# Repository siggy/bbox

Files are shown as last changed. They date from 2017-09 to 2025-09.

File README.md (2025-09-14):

# Beatboxer <!-- omit from toc -->

A human-sized drum machine built with a Raspberry Pi, an Adafruit Feather SCORPIO, NeoPixels, and Go.

- [Raspberry PI Setup](#raspberry-pi-setup)
  - [OS](#os)
    - [First Boot](#first-boot)
    - [Faster boot](#faster-boot)
    - [Code](#code)
    - [USB Audio](#usb-audio)
      - [bbox-style sound card](#bbox-style-sound-card)
      - [baux-style sound card](#baux-style-sound-card)
      - [Test](#test)
    - [Audio support for Go](#audio-support-for-go)
- [Run](#run)
- [Build](#build)
- [Auto boot with keyboard attach](#auto-boot-with-keyboard-attach)
  - [Auto boot baux](#auto-boot-baux)
- [Connectivity](#connectivity)
  - [Configure to connect over ethernet](#configure-to-connect-over-ethernet)
  - [Configure the Pi to connect as Wifi AP](#configure-the-pi-to-connect-as-wifi-ap)
    - [Switch the Pi back to connecting to the internet with wifi](#switch-the-pi-back-to-connecting-to-the-internet-with-wifi)
- [Docs](#docs)
- [Credits](#credits)
- [TODO](#todo)

# Raspberry PI Setup

## OS

1. Install Raspberry Pi Imager: https://www.raspberrypi.com/software/
2. Choose `Raspberry Pi 5`, `Raspberry Pi OS Lite (64-bit)` and
   `USB Mass Storage` in the Imager
3. Select:
  - `Set hostname` to `raspberrypi`
  - `Set username and password`: `sig`
  - `Set locale` to `en_US.UTF-8`
  - `Configure wireless LAN`
  - `Enable SSH`: `Allow public-key authentication only`

### First Boot

```bash
HOSTNAME=raspberrypi
HOSTNAME=raspberrypi5-2
HOSTNAME=raspberrypi5-3
HOSTNAME=raspberrypi5-4
HOSTNAME=raspberrypi5-5
HOSTNAME=raspberrypi5-6

ssh sig@raspberrypi.local
ssh sig@$HOSTNAME.local
ssh sig@raspberrypi5-5.local

# install packages
sudo apt-get update
sudo sed -i 's/^# *\(en_US.UTF-8 UTF-8\)/\1/' /etc/locale.gen
sudo locale-gen
sudo dpkg-reconfigure locales
sudo apt-get install -y git tmux vim locales

# GITHUB_TOKEN=

git clone https://github.com/siggy/dotfiles.git ~/code/dotfiles
cp ~/code/dotfiles/.local.bash.pi ~/.local.bash
cp ~/code/dotfiles/.curlrc        ~/
cp ~/code/dotfiles/.gitconfig     ~/
cp ~/code/dotfiles/.tmux.conf     ~/
cp ~/code/dotfiles/.vimrc         ~/
cp ~/code/dotfiles/.wgetrc        ~/

sed -i '/^[[:space:]]*helper = osxkeychain/ s/^/#/' ~/.gitconfig

mkdir -p ~/.vim/backups
mkdir -p ~/.vim/swaps
cp -a ~/code/dotfiles/.vim/colors ~/.vim

echo "[[ -s ${HOME}/.local.bash ]] && source ${HOME}/.local.bash" >> ~/.profile
```

### Faster boot

```bash
sudo systemctl disable ModemManager.service
sudo systemctl disable NetworkManager-wait-online.service
sudo systemctl disable bluetooth.service
sudo systemctl disable dphys-swapfile.service
sudo systemctl disable fake-hwclock.service
sudo systemctl disable systemd-binfmt.service
sudo systemctl mask sys-kernel-debug.mount sys-kernel-tracing.mount
sudo systemctl mask rpi-eeprom-update
sudo systemctl disable e2scrub_reap.service
sudo dphys-swapfile swapoff
sudo apt-get -y purge modemmanager bluez triggerhappy
sudo apt-get -y autoremove --purge

sudo grep -q 'rootdelay=' /boot/firmware/cmdline.txt \
  || sudo sed -i 's/$/ rootdelay=2 modules-load=dwc2/' /boot/firmware/cmdline.txt

echo "PollIntervalMinSec=600" | sudo tee -a /etc/systemd/timesyncd.conf
```

### Code

```bash
curl -L -o /tmp/go1.24.4.linux-arm64.tar.gz https://go.dev/dl/go1.24.4.linux-arm64.tar.gz
sudo rm -rf /usr/local/go && sudo tar -C /usr/local -xzf /tmp/go1.24.4.linux-arm64.tar.gz
export PATH=$PATH:/usr/local/go/bin

mkdir -p ~/code/
git clone https://github.com/siggy/bbox.git ~/code/bbox
```

### USB Audio

#### bbox-style sound card

For MCSPER USB to 3.5mm Audio Jack Adapter.

Plug in USB audio device and run:
```bash
sudo tee /etc/asound.conf > /dev/null <<'EOF'
pcm.!default {
  type plug
  slave.pcm "dmix:Audio,0"
}

ctl.!default {
  type hw
  card "Audio"
}
EOF

amixer
amixer -c 0 scontrols
amixer -c 0 set PCM 95%
```

#### baux-style sound card

For Plugable USB Audio Adapter with 3.5mm Speaker-Headphone and Microphone Jack.

Plug in USB audio device and run:
```bash
sudo tee /etc/asound.conf > /dev/null <<'EOF'
pcm.!default {
  type plug
  slave.pcm "dmix:Device,0"
}

ctl.!default {
  type hw
  card "Device"
}
EOF
```

#### Test

```bash
aplay /usr/share/sounds/alsa/Front_Center.wav
```

### Audio support for Go

```bash
sudo apt-get install -y libasound2-dev
```

# Run

```bash
go run cmd/bbox/main.go --fake-leds
```

# Build

```bash
go build -o /home/sig/bin/bbox cmd/bbox/main.go
```

# Auto boot with keyboard attach

```bash
cat <<'EOF' >> ~/.profile

if [ "$(tty)" = "/dev/tty1" ]; then
  tmux attach -t bbox || tmux new-session -s bbox "bash -c '/home/sig/bin/bbox; exec bash'"
fi
EOF
```

```bash
sudo mkdir -p /etc/systemd/system/getty@tty1.service.d
cat <<EOF | sudo tee /etc/systemd/system/getty@tty1.service.d/override.conf
[Service]
ExecStart=
ExecStart=-/sbin/agetty --autologin sig --noclear %I \$TERM
EOF

sudo systemctl daemon-reload
sudo reboot
```

## Auto boot baux

```bash
cat <<'EOF' >> ~/.profile

export MINIAUDIO_ALSA_NO_MMAP=1
if [ "$(tty)" = "/dev/tty1" ]; then
  tmux attach -t bbox || tmux new-session -s bbox "bash -c '/home/sig/bin/baux; exec bash'"
fi
EOF
```

# Connectivity

## Configure to connect over ethernet

```bash
IP=192.168.2.2
IP=192.168.2.3
IP=192.168.2.4
IP=192.168.2.5
IP=192.168.2.6
sudo nmcli con add type ethernet ifname eth0 con-name eth0-static ipv4.addresses $IP/24 ipv4.method manual
sudo nmcli con up eth0-static
```

```bash
HOSTNAME=raspberrypi
HOSTNAME=raspberrypi5-2
HOSTNAME=raspberrypi5-3
HOSTNAME=raspberrypi5-4
HOSTNAME=raspberrypi5-5
HOSTNAME=raspberrypi5-6
IP=192.168.2.2
IP=192.168.2.2
IP=192.168.2.3
IP=192.168.2.4
IP=192.168.2.5
IP=192.168.2.6
alias pi="ssh sig@$HOSTNAME.local"
alias pieth="ssh sig@$IP"
```

## Configure the Pi to connect as Wifi AP

```bash
SSID=sigpi
SSID=sigpi5-2
SSID=sigpi5-3
SSID=sigpi5-4
SSID=sigpi5-5
SSID=sigpi5-6
rfkill list
sudo rfkill unblock wifi
rfkill list
sudo nmcli radio wifi on
sudo nmcli dev wifi hotspot ifname wlan0 ssid $SSID password showmethepi
nmcli dev wifi show-password
sudo nmcli connection modify Hotspot autoconnect yes
```

From laptop:
```bash
HOSTNAME=raspberrypi5-4
ssh sig@$HOSTNAME.local
```

### Switch the Pi back to connecting to the internet with wifi

```bash
nmcli connection show
sudo nmcli connection down Hotspot
```

# Docs

```bash
docker run --rm \
  --volume="$PWD/docs:/srv/jekyll:Z" \
  --publish 4000:4000 \
  --publish 35729:35729 \
  -it jekyll/jekyll:4.2.2 \
  jekyll serve --source /srv/jekyll --livereload

open http://0.0.0.0:4000/bbox/
```

# Credits

- [amplitude](pkg/amplitude) courtesy of (https://github.com/johnusher)
- Hardware keyboard courtesy of (https://github.com/kodachi614/macropaw)
- [wavs](wavs) courtesy of (http://99sounds.org/drum-samples/)

# TODO

- proper LED simulator

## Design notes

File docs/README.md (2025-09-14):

---
layout: default
title: "Beatboxer: A human-sized drum machine built with a Raspberry Pi, a Feather SCORPIO, NeoPixels, and Go"
permalink: /
---

<style>
  :root { color-scheme: dark; }
  html, body, h1, h2 { background:#202124; color:#619e4e; }
  a { color:#b88de3; }
  a:visited { color:#a774d6; }
  pre, code { background:#111; color:#619e4e; }
  hr { border-color:#333; }
</style>

# Beatboxer: A human-sized drum machine built with a Raspberry Pi, a Feather SCORPIO, NeoPixels, and Go

<iframe width="560" height="315" src="https://www.youtube.com/embed/MepepCV4EUw" frameborder="0" allowfullscreen></iframe>

# Prior Art

Inspired by Nine Inch Nails' Echoplex drum machine:

<iframe width="560" height="315" src="https://www.youtube.com/embed/6O_92BTrUcA" frameborder="0" allowfullscreen></iframe>
---
First implementation in JavaScript at [sig.gy/beatboxer](https://sig.gy/beatboxer):

<iframe width="900" height="315" src="https://sig.gy/beatboxer" frameborder="0" allowfullscreen></iframe>

# Hardware

- [Raspberry Pi 5](https://www.raspberrypi.com/products/raspberry-pi-5/)
- [Adafruit Feather RP2040 SCORPIO](https://www.adafruit.com/product/5650)
- 8x [NeoPixel 144 strands](https://www.adafruit.com/product/2847)
- [Custom MacroPaw keyboard](https://github.com/kodachi614/macropaw) by [@kodachi614](https://github.com/kodachi614)

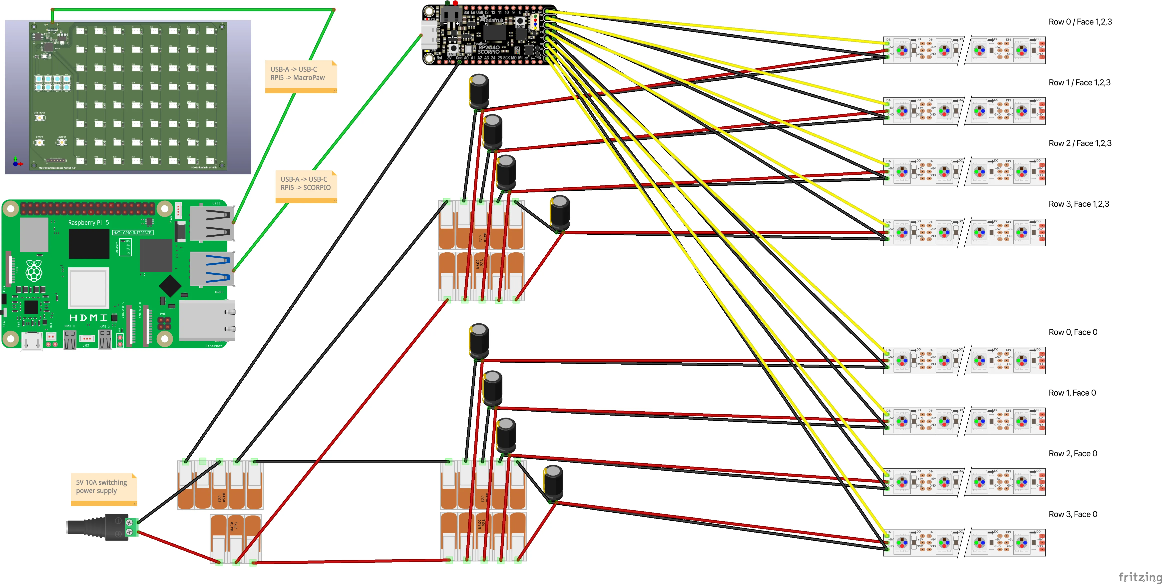
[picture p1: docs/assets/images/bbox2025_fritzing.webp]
Beatboxer 2025 Fritzing


<a href="assets/images/bbox2025_fritzing.fzz">Click here</a> to download the source Fritzing sketch file (requires the <a href="https://github.com/adafruit/Fritzing-Library">Adafruit Fritzing Library</a> and a <a href="https://github.com/siggy/macropaw/blob/main/Beatboxer/renders/macropaw_beatboxer_small.fzpz">custom MacroPaw part</a>).

# Software

- [main.go](https://github.com/siggy/bbox/blob/main/cmd/bbox/main.go)
- [generic program interface](https://github.com/siggy/bbox/blob/main/pkg/program/program.go#L16-L32)
- [SCORPIO integration](https://github.com/siggy/bbox/tree/main/scorpio)

# Build photos

<a
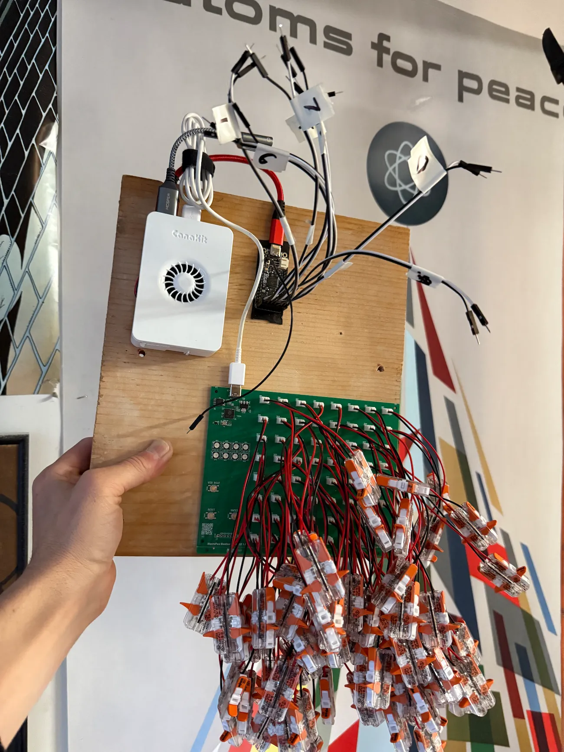
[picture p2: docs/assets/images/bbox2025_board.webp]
System on a board
href="assets/images/bbox2025_board.webp" data-lightbox="bbox2025" data-title="System on a board"></a><a
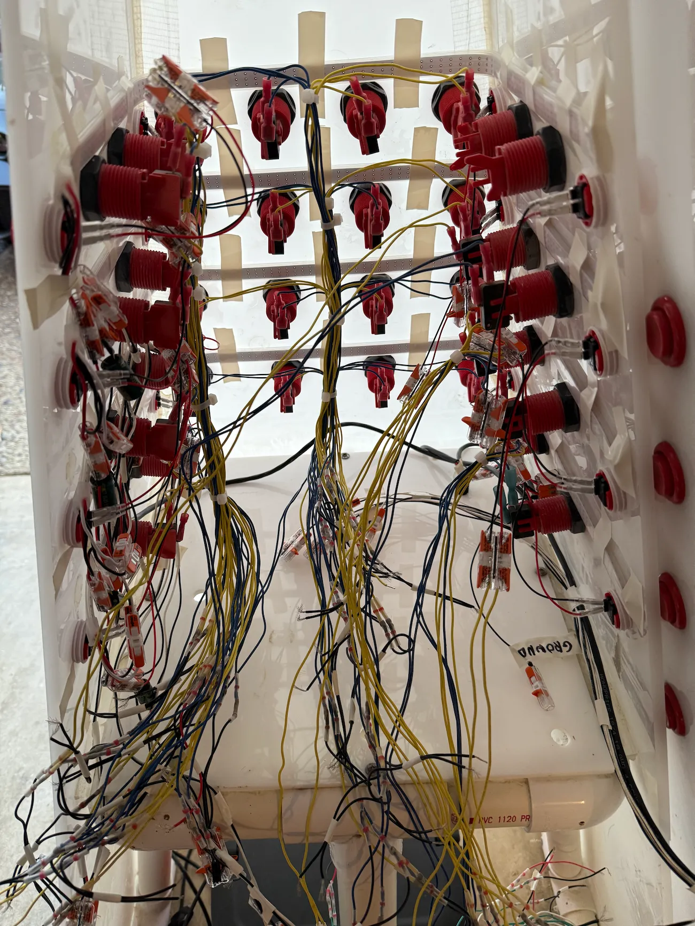
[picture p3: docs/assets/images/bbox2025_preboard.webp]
Pre-board installation
href="assets/images/bbox2025_preboard.webp" data-lightbox="bbox2025" data-title="Pre-board installation"></a><a
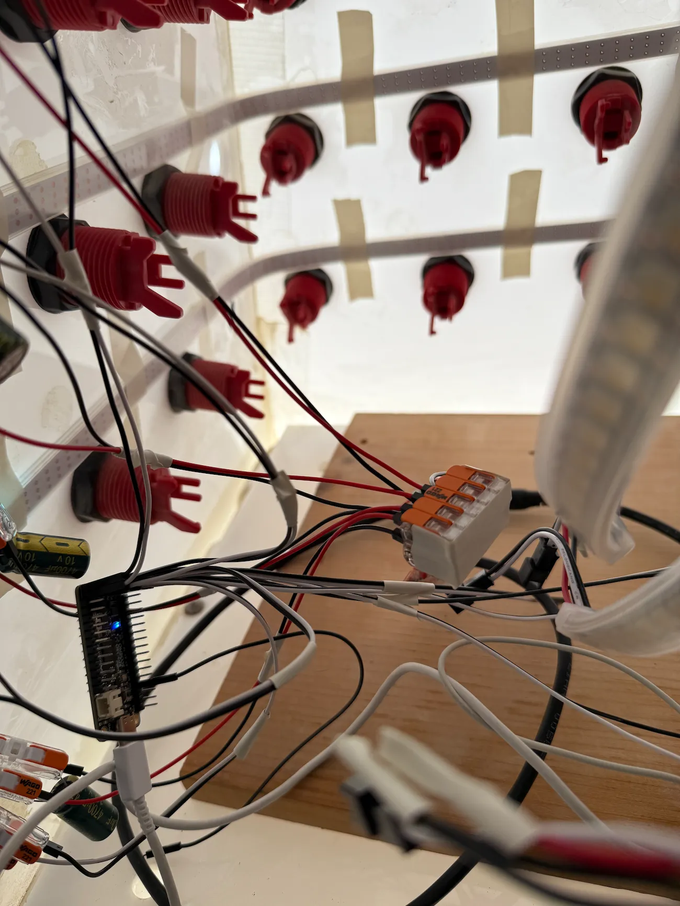
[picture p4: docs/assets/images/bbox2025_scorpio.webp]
SCORPIO install
href="assets/images/bbox2025_scorpio.webp" data-lightbox="bbox2025" data-title="SCORPIO install"></a><a
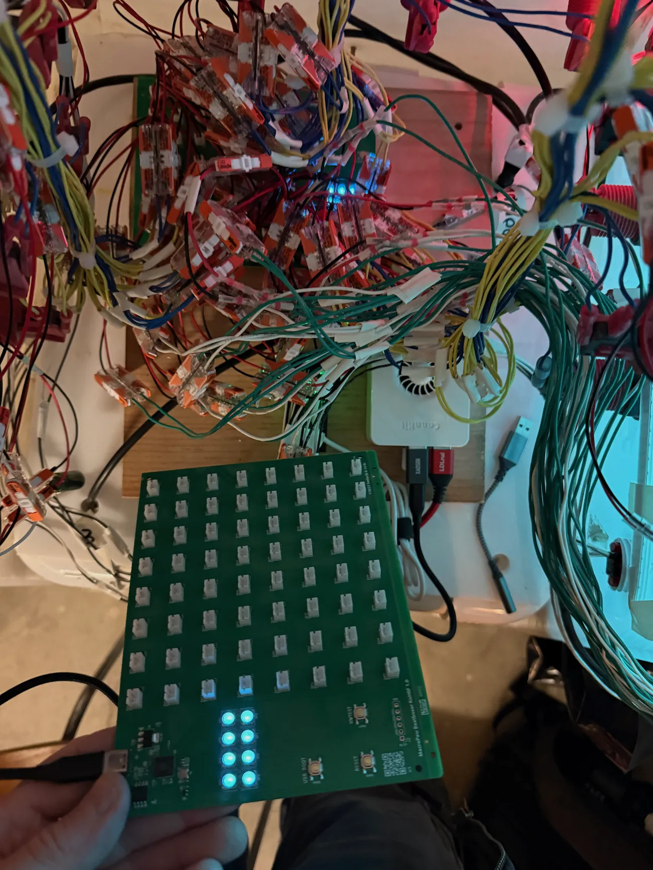
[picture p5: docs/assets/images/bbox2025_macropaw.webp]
MacroPaw install
href="assets/images/bbox2025_macropaw.webp" data-lightbox="bbox2025" data-title="MacroPaw install"></a><a
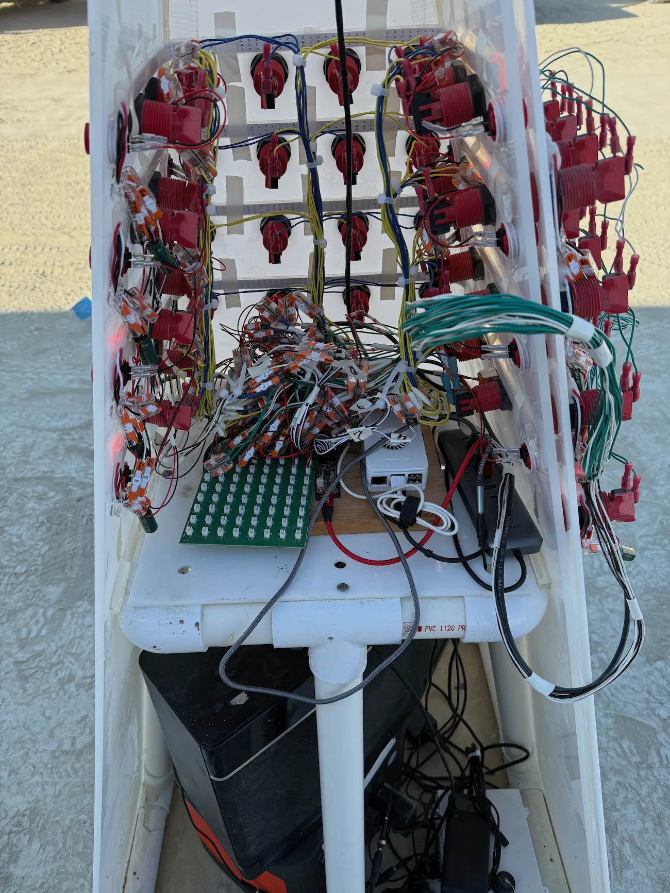
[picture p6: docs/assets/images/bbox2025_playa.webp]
Complete on playa
href="assets/images/bbox2025_playa.webp" data-lightbox="bbox2025" data-title="Complete on playa"></a><a
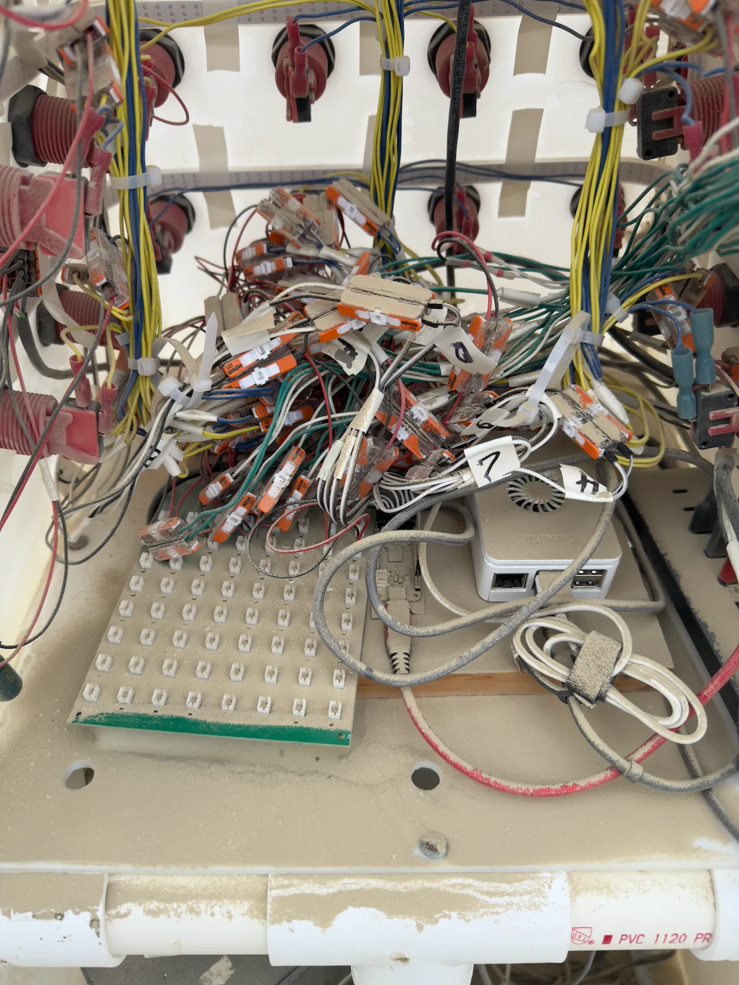
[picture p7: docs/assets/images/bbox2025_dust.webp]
After the dust storm
href="assets/images/bbox2025_dust.webp" data-lightbox="bbox2025" data-title="After the dust storm">
</a>

## Contact

<a href="https://github.com/siggy/bbox/issues">File an issue against this repo</a>, or find me at <a href="https://sig.gy">sig.gy</a>

This doc updated for 2025. For the original 2017-2018 writeup, see [Beatboxer 2017-2018](2017-2018).

<script src="https://ajax.googleapis.com/ajax/libs/jquery/2.1.4/jquery.min.js"></script>
<script src="assets/js/lightbox.min.js"></script>

<script>
  (function(i,s,o,g,r,a,m){i['GoogleAnalyticsObject']=r;i[r]=i[r]||function(){
  (i[r].q=i[r].q||[]).push(arguments)},i[r].l=1*new Date();a=s.createElement(o),
  m=s.getElementsByTagName(o)[0];a.async=1;a.src=g;m.parentNode.insertBefore(a,m)
  })(window,document,'script','https://www.google-analytics.com/analytics.js','ga');
  ga('create', 'UA-27834075-1', 'auto');
  ga('send', 'pageview');
</script>

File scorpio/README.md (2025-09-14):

# SCORPIO setup

## Configure board for Arduino

1. Arduino > Preferences
2. Add https://github.com/earlephilhower/arduino-pico/releases/download/global/package_rp2040_index.json
3. Boards Manager -> Raspberry Pi Pico/RP2040
4. Boards -> Adafruit Feather RP2040 SCORPIO
5. Sketch -> Include Library -> Manage Libraries ->
   - Adafruit_NeoPXL8
   - Adafruit_NeoPixel
   - Adafruit_ZeroDMA

## Arduino programs for SCORPIO

- [bbox.ino](bbox.ino): Main Beatboxer program.
- [baux.ino](baux.ino): Auxilliary Beatboxer program for driving the base and globe.
- [strand.ino](strand.ino): Standalone NeoPixel strand experiment.

## Debug from Pi

```bash
sudo fuser -v /dev/ttyACM0

sudo apt install picocom
picocom --baud 115200 /dev/ttyACM0
```

## Protocol

### Physical & Serial Settings

- Connection: USB‑CDC data port (/dev/ttyACM1 on the Pi, enabled via usb_cdc.enable(data=True) on the SCORPIO)
- Baud Rate: 115200 baud
- Data Bits: 8
- Parity: none
- Stop Bits: 1
- Flow Control: none

### Packet Framing

```
┌────────┬────────────┬───────────────┬───────────┐
│ 0xAA   │ 2-byte LEN │   PAYLOAD     │ CHECKSUM  │
│ Start  │ Big‑endian │ (LEN bytes)   │ 1 byte    │
└────────┴────────────┴───────────────┴───────────┘
```

1. Start Marker: 0xAA (1 byte)
2. Length: two‑byte unsigned integer, high‑byte first, total number of payload bytes
3. Payload: a sequence of N × 6 bytes (see §3)
4. Checksum: single byte = XOR of all payload bytes

### Payload Format

```
┌──────────┬──────────────┬───────┬───────┬───────┬───────┐
│ STRIP_ID │ PIXEL_INDEX  │  R    │  G    │  B    │  W    │
│  (0–7)   │ (0–length‑1) │(0–255)│(0–255)│(0–255)│(0–255)│
└──────────┴──────────────┴───────┴───────┴───────┴───────┘
```

- STRIP_ID (byte): Which NeoPixel strip (0…7)
- PIXEL_INDEX (byte): Which pixel on that strip
- R, G, B, W (bytes): The four color components

### Checksum

```go
var checksum byte
for _, b := range payload {
    checksum ^= b
}
```

### Sequence diagram

```
Pi (Go)                               SCORPIO
───────                               ───────

 every 30 ms tick:
   ┌───────────────────┐
   │ build diff list   │
   │ serialize payload │
   └───┬───────────────┘
       │ write([0xAA…])               loop:
       │────────────────────────────▶ check in_waiting
       │                              read start byte
       │                              read length bytes
       │                              read payload
       │                              read checksum
       │                              verify checksum
       │                              for each 6‑byte group:
       │                              └─update strip[pixel]
       │                              show() on all strips
```

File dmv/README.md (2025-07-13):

# DMV

Instructions for running DMV's LEDs.

## Arduino IDE

### Install

https://www.arduino.cc/en/software/

### Configure

Arduino Nano
Processor	ATmega328P (Old Bootloader)
Port: `/dev/cu.usbserial-110`

Install Adafruit NeoPixel library

### Install WS2812FX

```bash
git clone https://github.com/kitesurfer1404/WS2812FX.git
cp -a WS2812FX/src ~/Documents/Arduino/libraries/WS2812FX
```

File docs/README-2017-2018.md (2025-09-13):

---
layout: default
title: "Beatboxer: A human-sized drum machine built with a Raspberry Pi, LEDs, and Go"
permalink: /2017-2018
---

# Beatboxer: A human-sized drum machine built with a Raspberry Pi, LEDs, and Go

This is the story of building Beatboxer:

## 2017

<iframe width="560" height="315" src="https://www.youtube.com/embed/2gNIAz0s2dg" frameborder="0" allowfullscreen></iframe>

## 2018

<iframe width="560" height="315" src="https://www.youtube.com/embed/dJoFQYvSYmA" frameborder="0" allowfullscreen></iframe>

## Prior Art

### Nine Inch Nails

Around 2008 I saw Nine Inch Nails perform Echoplex using a drum machine that occupied the entire stage:

<iframe width="560" height="315" src="https://www.youtube.com/embed/6O_92BTrUcA" frameborder="0" allowfullscreen></iframe>

I loved it, I wanted to build something like it.

### Raspberry Pi

Eight years later in 2016 I had a converstion with my friend [Nick](https://github.com/hebnern) about his Arduino integration into [The Krawler](https://www.facebook.com/thekrawler/)'s fire poofers, he mentioned the lack of library and developer support being a pain point. He said he'd use a Raspberry Pi the next time, since it's pretty much just a Linux computer. This caught my attention. _It's a UNIX system, I know this._ That was the catalyst to look for an excuse to play with a Pi.

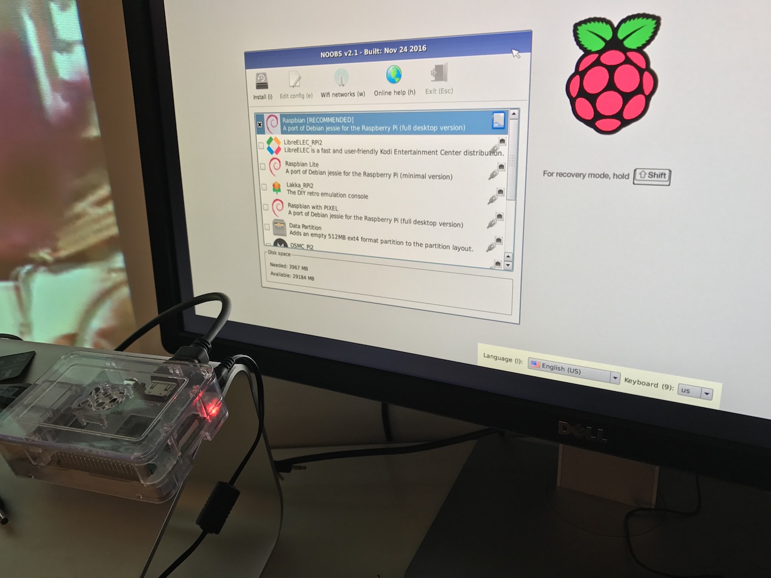
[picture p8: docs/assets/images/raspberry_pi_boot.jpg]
Raspberry Pi Boot
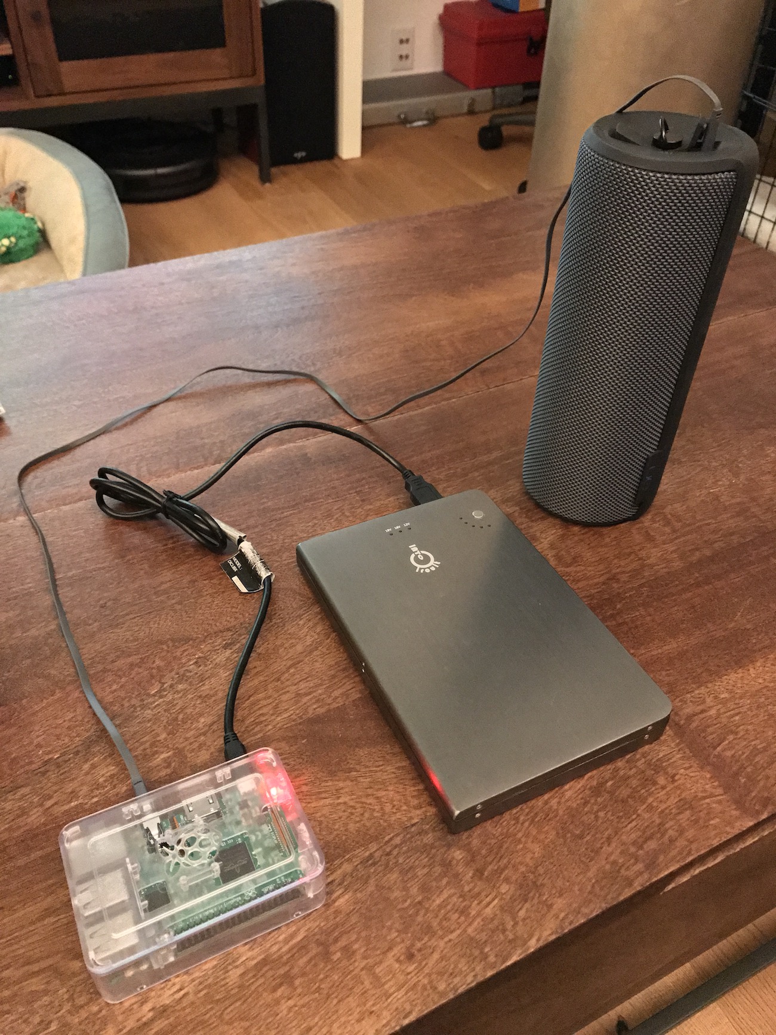
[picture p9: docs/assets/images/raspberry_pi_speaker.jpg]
Raspberry Pi Speaker
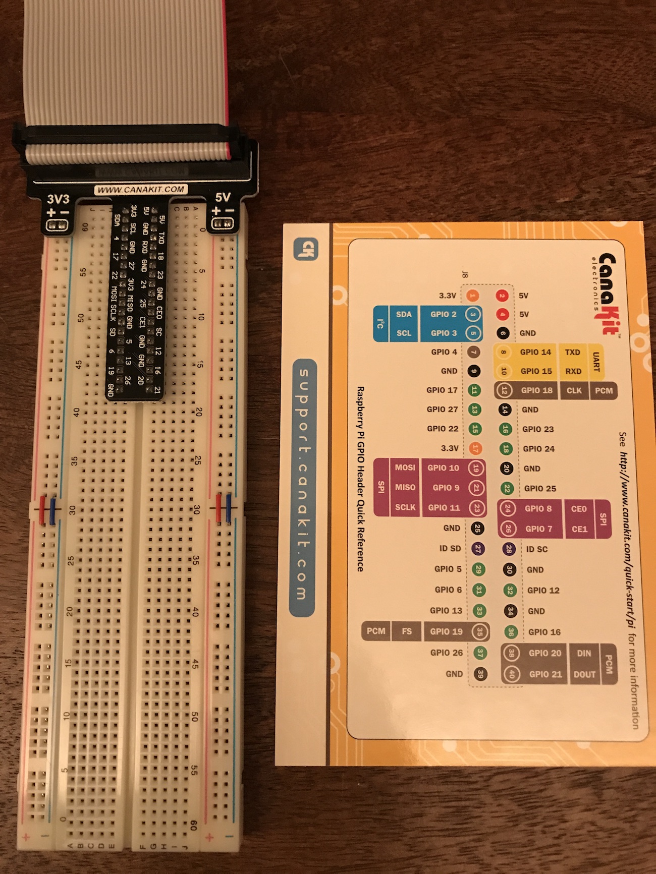
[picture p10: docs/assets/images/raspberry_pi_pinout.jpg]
Raspberry Pi Pinout


### Beatboxer in JavaScript

<a href="https://github.com/siggy/beatboxer/commit/17850ff889e607aba5941c5de58ecba9b342d5c0">About a week</a> after chatting with Nick, I attempted to replicate Nine Inch Nails' drum machine on a web page, using as little code as possible. The result was a few hundred lines of JavaScript, HTML, and CSS, I called it [Beatboxer](https://sig.gy/beatboxer/):

<iframe width="900" height="315" src="https://sig.gy/beatboxer/" frameborder="0" allowfullscreen></iframe>

This was a fun project, I learned a bit about [AudioContext](https://developer.mozilla.org/en-US/docs/Web/API/AudioContext) for playing sounds and [requestAnimationFrame](https://developer.mozilla.org/en-US/docs/Web/API/window/requestAnimationFrame) for timing.

## A rewrite in Go

[Go](https://golang.org/) has recently become a favorite programming language of mine. Rewriting Beatboxer in Go was a great excuse to play with the language a bit more.

Beatboxer transmits input from a keyboard to LEDs, a console renderer, and a drum loop. The Go language really shines here in allowing explicit definition of these concurrent threads, with communication via Go Channels. This whole architecture is summarized nicely in [Beatboxer's main](https://github.com/siggy/bbox/blob/master/cmd/bbox.go).

Reading and playing back audio files in Go turned out to be more work than in JavaScript. I eventually found a pair of excellent Go libraries, [youpy's go-wav](https://github.com/youpy/go-wav) for reading wavs, and [gordonklaus' Go bindings](https://github.com/gordonklaus/portaudio) for [PortAudio](http://portaudio.com/) for outputting sound.

I found an awesome collection of high quality drum samples at [99sounds.org](http://99sounds.org/drum-samples/). It's free for download. Throw them a donation if you appreciate their work. I found their 808 beats to be just want I needed. I reached out to confirm they were OK with me using their samples in a public art project, [Tomislav](https://twitter.com/bpblog) replied a few hours later with full support.

## Back to hardware

With a working prototype in Go, I returned to thinking about building a physical drum machine. [Burning Man 2017](https://burningman.org/) provided a concrete deadline for added motivation.

I began brainstorming a structure with my good friend [@yet](https://twitter.com/yet), who pointed out that a long, flat structure like the one used by Nine Inch Nails would not fare well in the gale-force winds of the Black Rock Desert. He suggested wrapping the drum machine into the shape of a phone booth, as a more compact structure would be much easier to build, transport, and support.

A few days later I described the project to my good friend [Jhon](http://www.jar-lab.com/). Jhon's background in electronics and industrial design exceeds just about anyone I know, and he immediately suggested I reshape the phone booth as a pyramid. I loved the idea. At the time I did not realize the added complexity a shape like this would require, but in the end it was worth it.

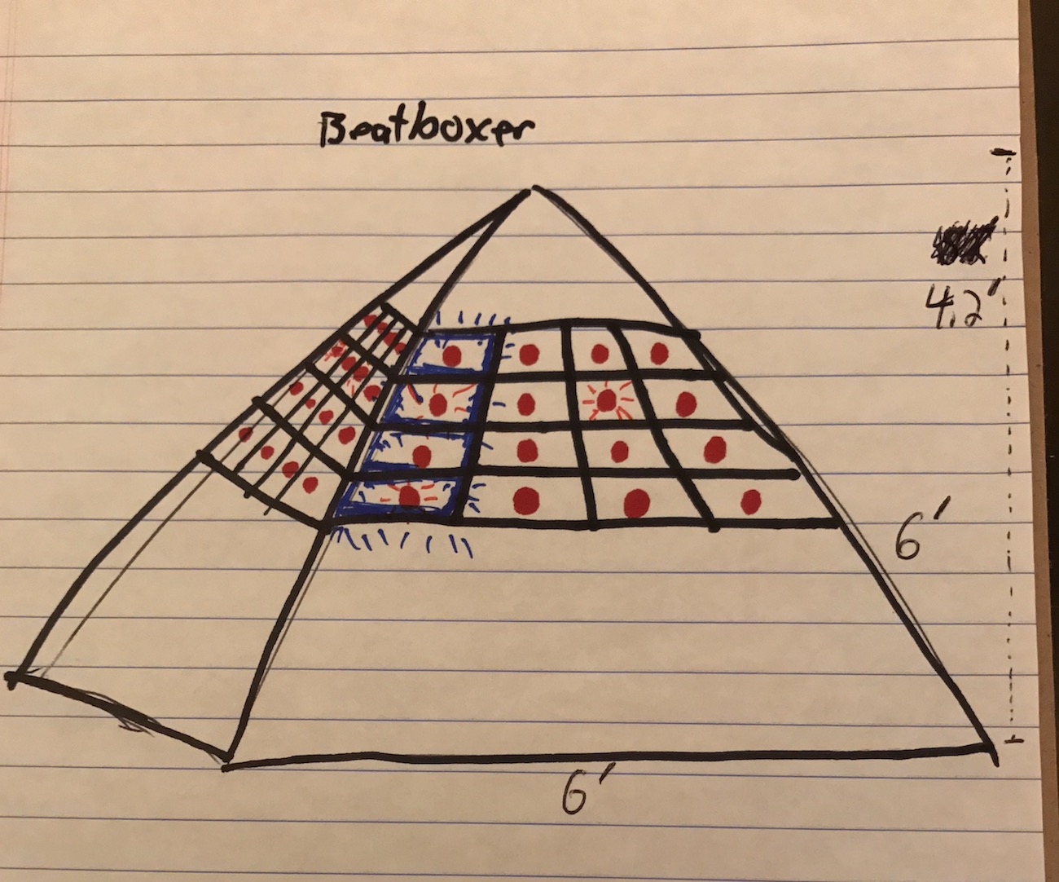
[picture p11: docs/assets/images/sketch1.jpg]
Sketch1
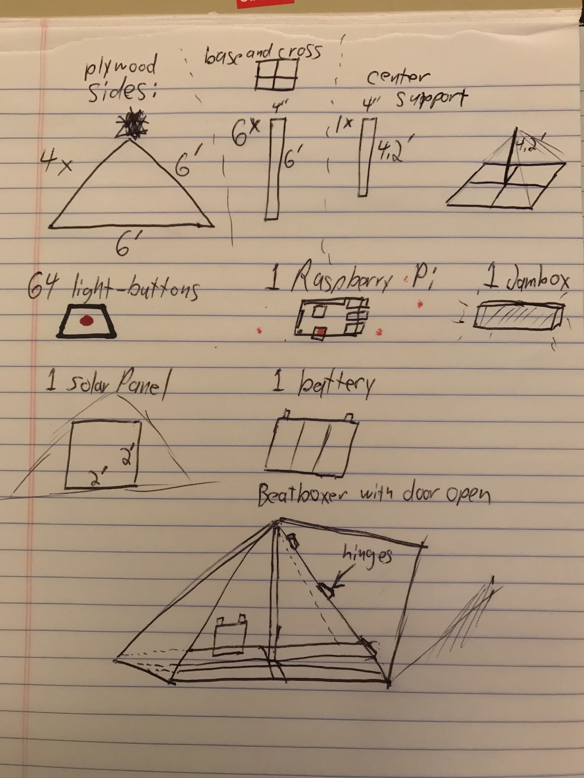
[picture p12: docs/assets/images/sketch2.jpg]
Sketch2
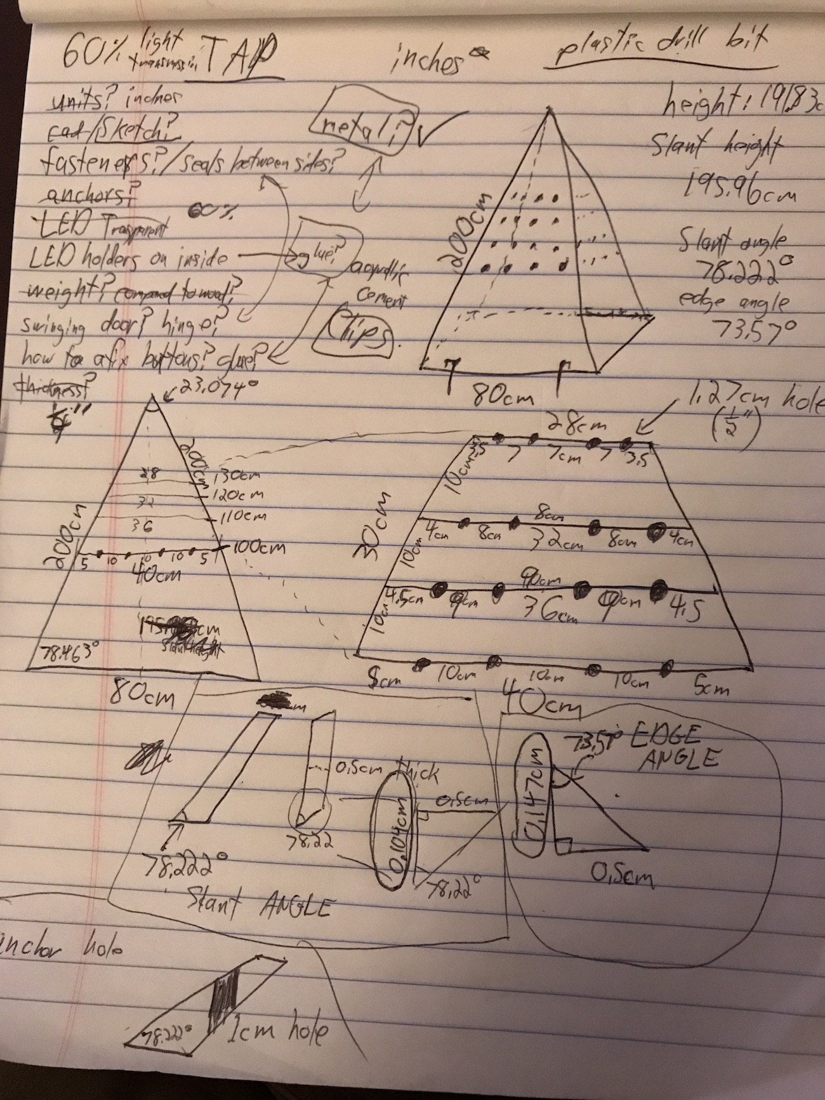
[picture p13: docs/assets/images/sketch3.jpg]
Sketch3


To build a pyramid, I naively thought I could simply design four triangles, do some linear calculations for the angles, and all would fit together. Fortunately my good friend and owner of Three Bears Furniture, [@jneaderhouser](https://twitter.com/jneaderhouser), pointed me to this excellent [compound miter calculator](http://www.pdxtex.com/canoe/compound.htm). This helped me determine that, based on triangles 6 feet tall by 2.5 feet wide, I needed 46.244° side bevels and 77.975° base bevels. I was able to confirm this all worked by building Beatboxer in SketchUp:

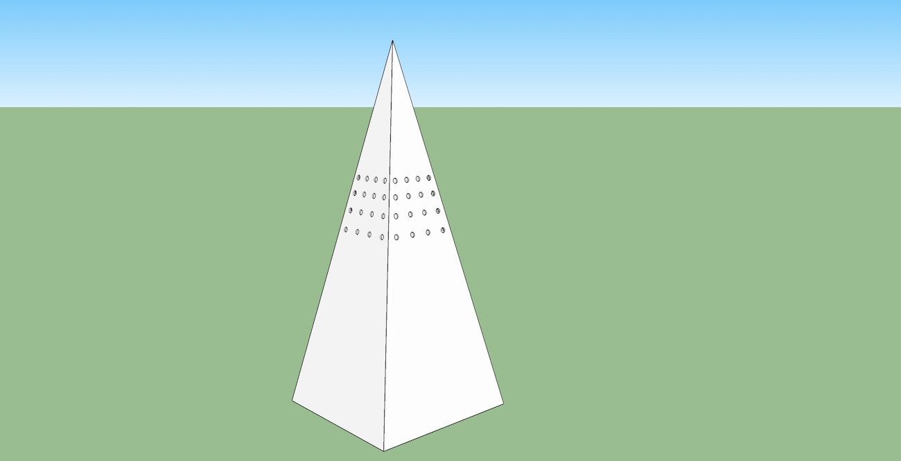
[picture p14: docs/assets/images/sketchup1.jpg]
SketchUp
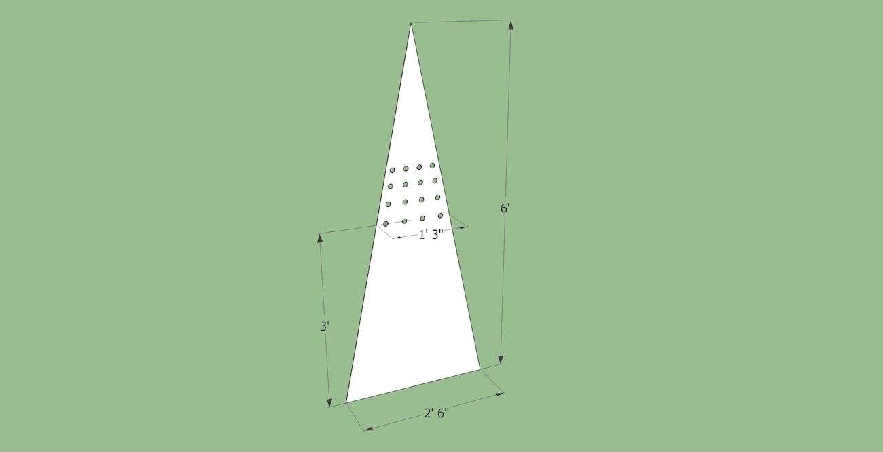
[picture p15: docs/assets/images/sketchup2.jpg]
SketchUp
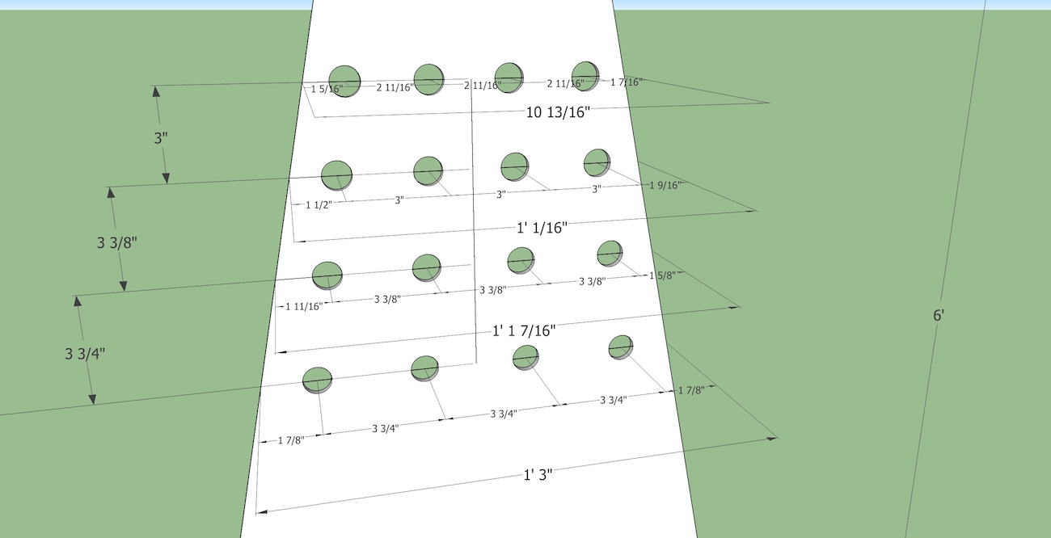
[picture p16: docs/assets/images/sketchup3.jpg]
SketchUp


For the full <a href="https://www.sketchup.com/">SketchUp</a> file, <a href="assets/images/bbox_sketchup.skp">click here</a>.

### Addressable LEDs

As the physical form continued to coalesce, I knew I'd need buttons to enable beats, and LEDs to provide feedback. I began researching addressable LEDs. Like Go, this was another domain where I was looking for a personal project to enable learning more about. Arduino seemed to be the platform of choice for working with LEDs. I opted to build the project around a Pi, aware that I was going a bit against the grain.

Fortunately the amazing folks at [Adafruit](https://www.adafruit.com/) had a tutorial on [controlling NeoPixel LEDs with a Raspberry Pi](https://learn.adafruit.com/neopixels-on-raspberry-pi). Even more fortuitious, the library used in the tutorial, [jgarff's rpi_ws281x](https://github.com/jgarff/rpi_ws281x), came with a Go wrapper!

I cannot emphasize enough how helpful [Adafruit](https://www.adafruit.com/) is for projects such as these. Their tutorials and documentation are awesome, and they provide all the materials needed to follow along.

Controlling [NeoPixels](https://www.adafruit.com/category/168) from a Pi requires building a circuit board, something I had zero experience with. I again enlisted [@yet](https://twitter.com/yet)'s help to learn how to solder wires, chips, and resistors. In short order we had a Pi controlling [NeoPixels](https://www.adafruit.com/category/168).

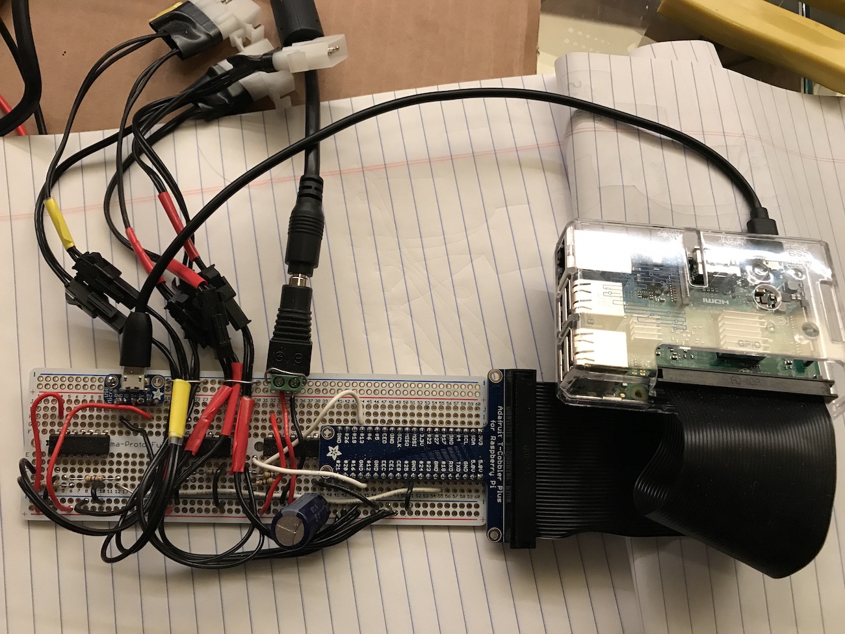
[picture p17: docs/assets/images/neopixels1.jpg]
NeoPixels1
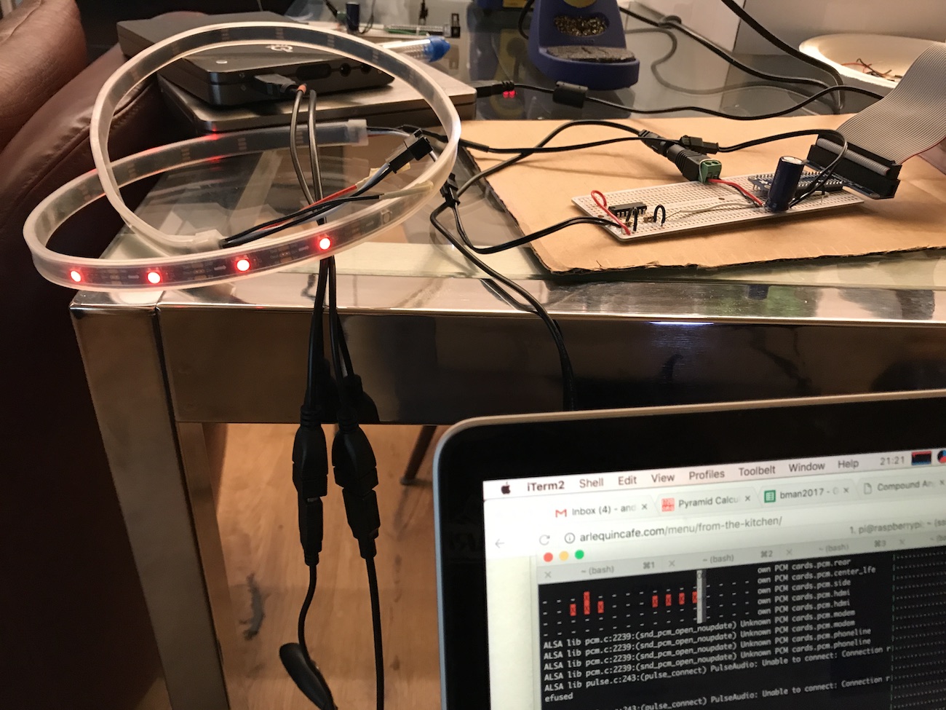
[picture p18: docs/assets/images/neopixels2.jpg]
NeoPixels2
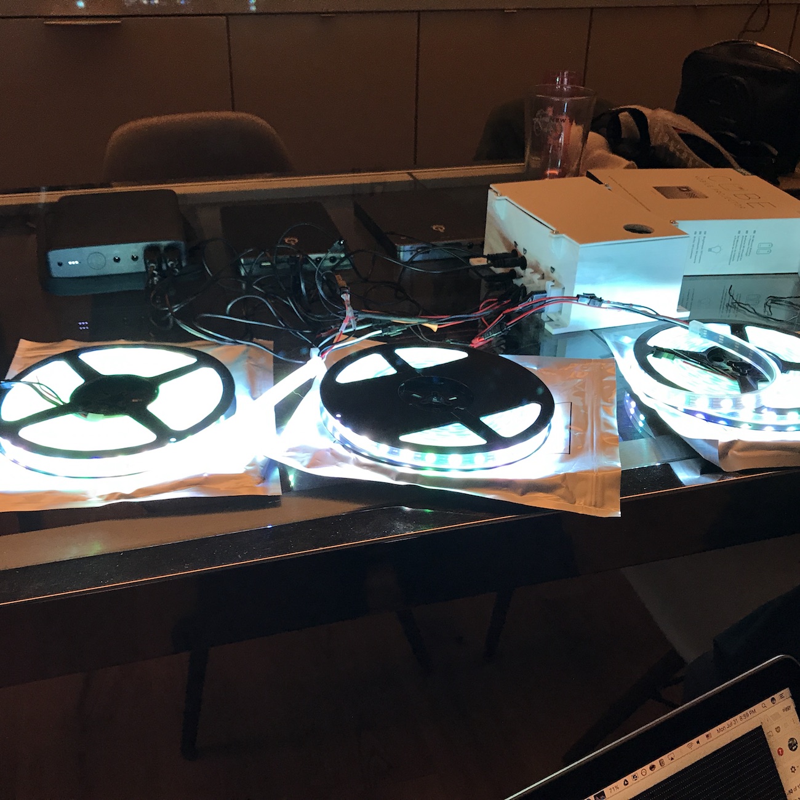
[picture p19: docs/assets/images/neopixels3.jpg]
NeoPixels3


### Pulse width modulation and onboard audio

The [rpi_ws281x LED library](https://github.com/jgarff/rpi_ws281x) uses hardware PWM on the Raspbery Pi to communicate with the LEDs. Unfortunately this [conflicts](https://github.com/jgarff/rpi_ws281x#pwm) with the Pi's onboard sound card. To get around this, I disabled the onboard sound and installed a [Plugable USB Audio Adapter](https://www.amazon.com/gp/product/B00NMXY2MO). For more details on the config changes, have a look at the `external sound card` section of [this repo's README.md](https://github.com/siggy/bbox#env--bootup).

### Keyboard hacking

For user input, I wanted to use 64 large buttons to toggle beats. The Pi does not have enough pins to handle this many without other chips or boards. I had read about hacking apart a computer keyboard and wiring buttons into it, via [Instructables](https://www.instructables.com/) in two articles: [Hacking a USB Keyboard](https://www.instructables.com/id/Hacking-a-USB-Keyboard/) and [Create External Buttons For Your Keyboard](https://www.instructables.com/id/Create-External-Buttons-For-Your-Keyboard/). This was a compelling option, as the software was already built to accept keyboard inputs, no additional coding or GPIO programming required. It's a fun hack, though wiring 64 buttons into a tiny keyboard PCB yields this tangle of epicness:

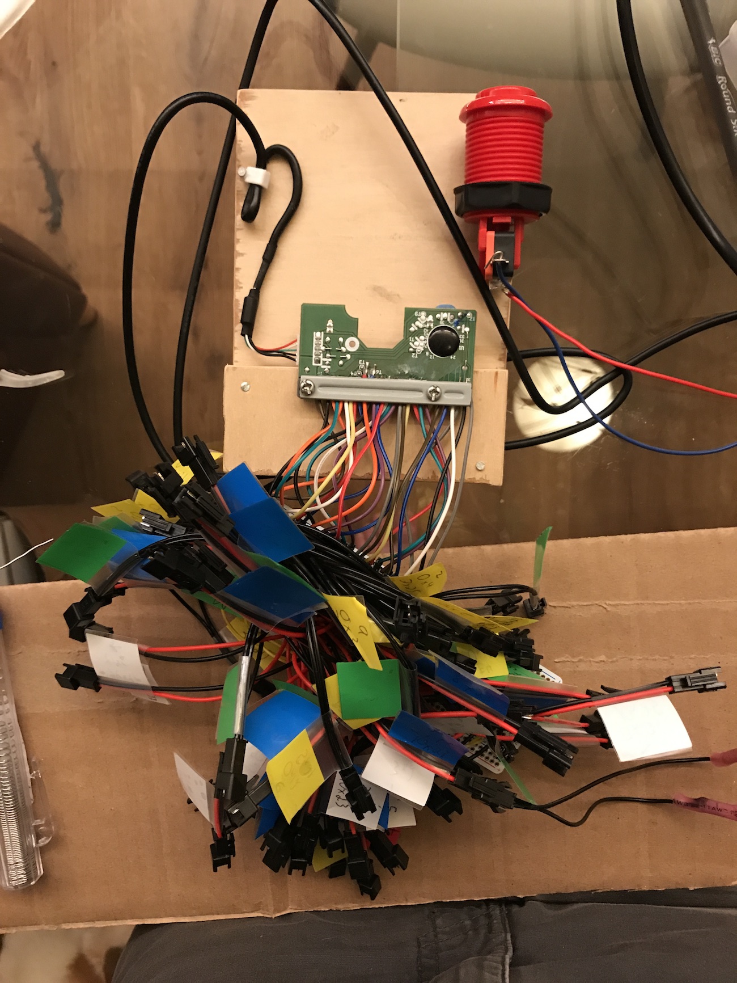
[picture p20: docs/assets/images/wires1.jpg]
Wires
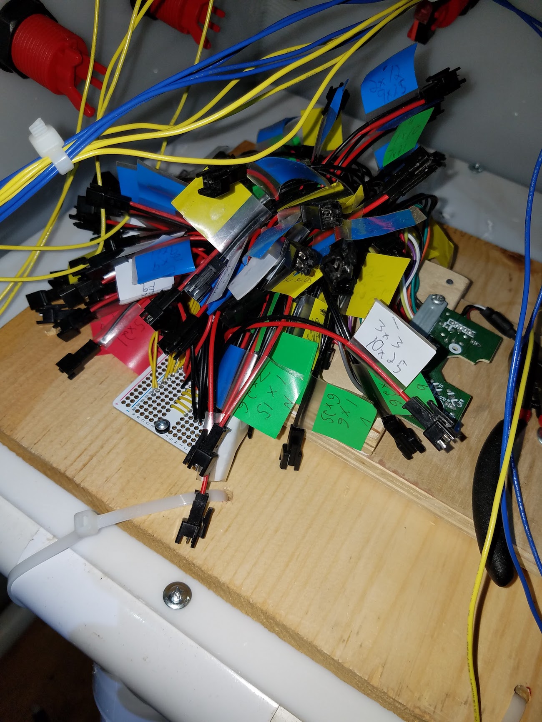
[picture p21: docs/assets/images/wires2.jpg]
Wires
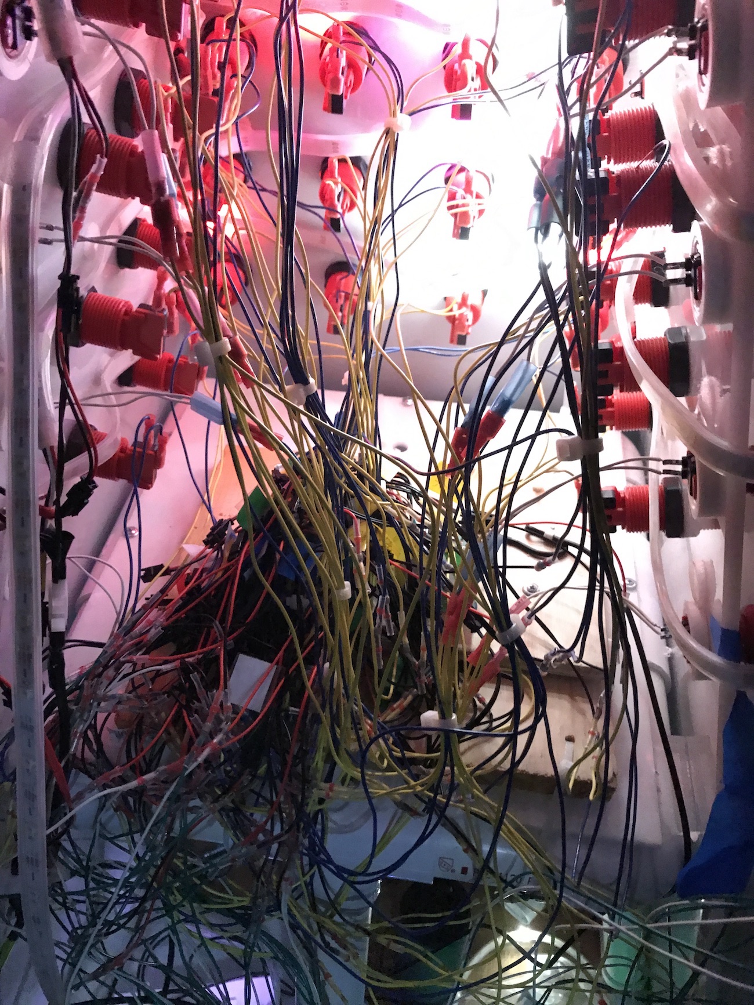
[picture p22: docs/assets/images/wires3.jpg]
Wires


Determined to hack this keyboard, I again enlisted much soldering help from [@yet](https://twitter.com/yet) to wire 30 pins from the keyboard pcb to an [Adafruit perma-proto board](https://www.adafruit.com/product/1606). From there we wired up 64 combinations of the 30 pins. For those interested in the pinouts of an [AmazonBasics Keyboard](https://www.amazon.com/gp/product/B005EOWBHC/ref=oh_aui_search_detailpage?ie=UTF8&psc=1), have a look at this [code](https://github.com/siggy/bbox/blob/master/bbox/keys.go).

### Plastics

In deciding on the material for the exterior of the pyramid, my friends [@yet](https://twitter.com/yet) and Brian MF Horton suggested plywood, but a desire for transparent material, to allow LEDs to shine through from the inside, led me to plastic. In the end we built the base and a halo out of plywood, as an homage to this initial design, and our shared fondness for [Tom Sachs' Love Letter to Plywood](https://vimeo.com/44947985).

I had no experience working with or manufacturing plastic. Fortunately, the good folks at [TAP Plastics SF](https://www.tapplastics.com/about/locations/detail/san_francisco_ca), and specifically my new friend at TAP, Jacobo, were extremely helpful in guiding me. I submitted the overall triangle dimensions for C&C manufacturing. The trickier part was producing those precise bevel angles so the triangles would fit together perfectly, and align with the ground. Jacobo took it upon himself to cut the bevels by hand. I had ordered up five triangles instead of four in case anything broke. I ended up with five perfectly shaped triangles. When put together, the four tops of the triangles fit with absolute precision, I cannot thank Jacobo and TAP enough for their work on this.

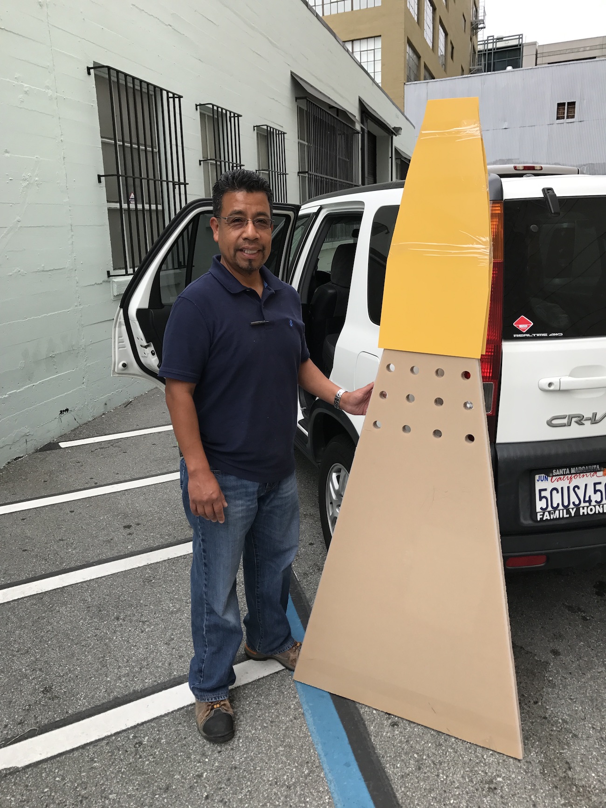
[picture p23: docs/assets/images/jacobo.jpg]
Jacobo from TAP Plastics
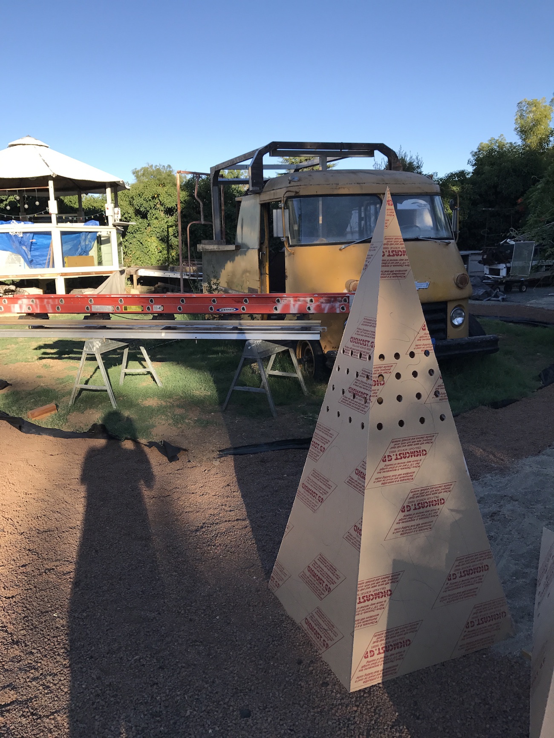
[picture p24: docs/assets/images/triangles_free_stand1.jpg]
Free-standing triangles
<a href="assets/images/triangles_free_stand2.jpg" data-lightbox="jacobo" data-title="Free-standing triangles">Free-standing triangles</a>

### Construction

With software, electronics, and materials proven out, last was actual assembly. As with all the collaboration on this project, I simultaneously realized I needed help and found a friend extremely willing to jump in. My friend Brian, who could build a house if he had to, and had experience constructing things to withstand the elements at Burning Man, understood well before I did what was required to assemble Beatboxer. I showed up at his house expecting to ask some questions, and he had a complete internal skeleton designed, with materials sourced and ready to assemble. In one evening we went from plastic pieces to a sturdy pyramid. Brian built a complete internal structure out of PVC pipes, very strong and lightweight.

<a href="assets/images/triangles_pancakes.jpg" data-lightbox="structure" data-title="Triangles and Pancakes">Triangles and Pancakes</a><a href="assets/images/structure1.jpg" data-lightbox="structure" data-title="PVC Structure">PVC Structure</a><a href="assets/images/structure2.jpg" data-lightbox="structure" data-title="PVC Structure">PVC Structure</a>

Without Brian's help I would have assembled this thing with glue and tape and it probably would have collapsed on day one.

### Last minute freakout

While helping me with bevel angles, my woodworker friend [@jneaderhouser](https://twitter.com/jneaderhouser) also advised me to build a prototype. I forewent this step in favor of SketchUp, concerned I did not have time for additional construction. One week before the event that decision came back to bite me. I had purchased 64 [red arcade buttons](https://www.amazon.com/gp/product/B00V0OM7WO/ref=oh_aui_search_detailpage?ie=UTF8&psc=1) to be mounted in the pyramid sides, which would toggle the beats. As I assembled Beatboxer for the first time, I quickly realized that the buttons were so deep that they collided on the corners of the pyramid. I needed shallower buttons, but the holes in the pyramid had been cut specifically for the diameter of these larger buttons. Again a friend, [@oceanphoto](https://twitter.com/oceanphoto), swooped in to save the day. He quickly 3D printed mountings to allow smaller buttons to fit tightly in the pyramid holes:

<a href="assets/images/3d_button1.jpg" data-lightbox="3d_button" data-title="3D-printed button housing">3D-printed button housing</a><a href="assets/images/3d_button2.jpg" data-lightbox="3d_button" data-title="3D-printed button housing">3D-printed button housing</a>

## The big event

With all the pieces in place, my good friends Rob and [@cecbayan](https://www.instagram.com/cecbayan/) provided some space on their trailer next to their insane riding-lawnmower-turned-tank, [The Krawler](https://www.facebook.com/thekrawler/), to transport Beatboxer from the Bay Area to the Black Rock Desert.

Upon arrival setup went surprisingly smooth. The awesome folks at [The Artery](https://burningman.org/event/art-performance/artist-resources/) guided us to our placement location. The rest of the week was spent swapping and charging batteries and speakers, which proved a bit more challenging due to Beatboxer getting a lot more use than anticipated (an exciting problem to have). In the end it was fully functional roughly 90% of the week, with outages only due to batteries. The structure, buttons, and electronics held up to the elements.

2017 and 2018, respectively:

<a href="assets/images/beatboxer_playa.jpg" data-lightbox="beatboxer_playa" data-title="Beatboxer On Playa">Beatboxer On Playa</a><a href="assets/images/beatboxer_playa_2018.jpg" data-lightbox="beatboxer_playa" data-title="Beatboxer On Playa 2018">Beatboxer On Playa 2018</a>

## Lessons learned

I originally set out to build Beatboxer on my own, to see if I could, and also because I did not want to burden friends who already had amazing projects on their own plates. Though I quickly found that I was in way over my head, I fortunately also found folks who were extremely willing to get involved. Without everyone jumping in, there is no way this project would have happened. I cannot thank everyone enough.

<iframe width="560" height="315" src="https://www.youtube.com/embed/a7bc4D5Lgos" frameborder="0" allowfullscreen></iframe>

## Epilogue

As I learned to work with LEDs, I found opportunities to work with other artists to help light their own projects. While Beatboxer used about 300 LEDs, these projects demanded a bit more. Applying the same powering methods to these larger projects resulted in some melted electronics, necessitating a power redesign. Fortunately my friend [Tom](http://www.tinsel.org/) quickly provided a wiring diagram to overcome these power issues:

<a href="assets/images/fish_fritzing.png" data-lightbox="fish_fritzing" data-title="The Fish Fritzing">The Fish Fritzing</a>

To download the source Fritzing shareable sketch file, <a href="assets/images/fish_fritzing.fzz">click here</a> (requires the <a href="https://github.com/adafruit/Fritzing-Library">Adafruit Fritzing Library</a>). To view this project directly on the Fritzing site, head over to the
<a href="http://fritzing.org/projects/neopixels-on-mutant-vehicles">NeoPixels on Mutant Vehicles project</a> at <a href="http://fritzing.org">fritzing.org</a>.

With additional components and design complexity, my friend [@oceanphoto](https://twitter.com/oceanphoto) jumped back in and 3D printed some awesome enclosures to keep everything safe from the elements, and even included ethernet ports to be able to update the Pi without opening the enclosures:

<a href="assets/images/enclosure1.jpg" data-lightbox="enclosure" data-title="Enclosure">Enclosure</a><a href="assets/images/enclosure2.jpg" data-lightbox="enclosure" data-title="Enclosure">Enclosure</a><a href="assets/images/enclosure3.jpg" data-lightbox="enclosure" data-title="Enclosure">Enclosure</a>

Another requirement for these projects was faster boot time. With vanilla Raspian I was seeing 30 second boot times. This was fine for Beatboxer where it was left running all night, but too long for a mutant vehicle that should be illuminated as soon as possible when it's turned on. I switched to Raspbian Lite and disabled as many services as I could, eventually getting boot time down to around 7 seconds. For full details on these config changes, have a look at the [First Boot section of this repo's README.md](https://github.com/siggy/bbox#first-boot).

With power and boot time sorted, we were ready to apply these LEDs to three more projects.

<a href="assets/images/fish_beatboxer.jpg" data-lightbox="epilogue" data-title="Fish and Beatboxer">Fish and Beatboxer</a>

### The Krawler

[The Krawler](https://www.facebook.com/thekrawler/) is Rob and [@cecbayan](https://www.instagram.com/cecbayan/)'s riding-lawnmower-turned-tank. It also shoots fire from eight poofers mounted on top. Here we added 480 LEDs along the bottom frame in a streak-like pattern, to highlight some of the amazing manufacturing and engineering that went into this vehicle.

<a href="assets/images/fish_krawler.jpg" data-lightbox="epilogue" data-title="Fish & Krawler">Fish & Krawler</a>

### Crane of Remembrance

The Crane of Remembrance is a 15-foot tall replica of a Port of Oakland crane, and a tribute to the victims of the [Ghost Ship Fire](https://en.wikipedia.org/wiki/2016_Oakland_warehouse_fire). Our friend Rob is an Oakland firefighter, and was onsite during the incident. He inspired our group to build the Crane. The lighting included 540 LEDs, 240 in a beating heart, and 300 in two strands extending across the top. The heart beats at 36 BPM, and the strands display 36 lights at a time, one for each person lost in the fire.

<a href="assets/images/crane.jpg" data-lightbox="epilogue" data-title="Crane Of Remembrance">Crane Of Remembrance</a>

### The Fish

The Fish is Brian's mutant vehicle, built on top of an airport luggage carrier. This year was the Fish's tenth year at Burning Man. This turned out to be the most ambitious lighting project, involving 2040 LEDs, all mounted in its four fins. Each side fin alone has 720 LEDs, and the top and back fins have a combined 600. Painting with LEDs on a canvas like this turned out to be quite a thrill:

<iframe width="560" height="315" src="https://www.youtube.com/embed/AYFAND0Bk_w" frameborder="0" allowfullscreen></iframe>

## Contact

Thanks for reading. If you have any questions or comments, you can <a href="https://github.com/siggy/bbox/issues">file an issue against this repo in Github</a>, or just hit me up on Twitter at <a href="https://twitter.com/siggy">@siggy</a>.

Published 2017.10.02. Updated 2019.05.17 with 2018 content.

## Beatboxer in real life

If you are interested in seeing Beatboxer in person, it will be on display Saturday, 2017.10.14 at <a href="https://burningman.org/events/san-francisco-decompression-2017/">SF Decompression</a>. Come say hi!

<script src="https://ajax.googleapis.com/ajax/libs/jquery/2.1.4/jquery.min.js"></script>
<script src="assets/js/lightbox.min.js"></script>

<script>
  (function(i,s,o,g,r,a,m){i['GoogleAnalyticsObject']=r;i[r]=i[r]||function(){
  (i[r].q=i[r].q||[]).push(arguments)},i[r].l=1*new Date();a=s.createElement(o),
  m=s.getElementsByTagName(o)[0];a.async=1;a.src=g;m.parentNode.insertBefore(a,m)
  })(window,document,'script','https://www.google-analytics.com/analytics.js','ga');
  ga('create', 'UA-27834075-1', 'auto');
  ga('send', 'pageview');
</script>

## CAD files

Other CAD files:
docs/assets/images/bbox_sketchup.skp

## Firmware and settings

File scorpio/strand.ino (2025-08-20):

/*
  Single-strand NeoPXL8 demo (pulses + twinkles)
  - Pulses: NO OVERLAP by position rule; spawn next after newest rear edge
            passes a random distance from the start (min MIN_PULSE_GAP_PX)
  - Smooth rendering: float accumulation + gamma + light temporal dithering
  - Twinkles: white channel, fixed rate; relocate each cycle, slow rise/fall
*/

#include <Adafruit_NeoPXL8.h>
#include <math.h>
#include <vector>

// ======== USER TUNABLES ========
#define STRAND_LEN 144
#define COLOR_ORDER NEO_GRBW
#define DATA_PIN 16

// Pulse motion
const float PULSE_SPEED = 4.0f; // px/sec

// Pulse size (HALF-length randomized); visible total ≈ 2*halfLen
const float PULSE_HALFLEN_MIN_PX = 1.0f;
const float PULSE_HALFLEN_MAX_PX = 7.0f;

// Spacing rule: spawn next pulse when the newest pulse's REAR edge (leftmost)
// has traveled at least: MIN_PULSE_GAP_PX + random(0..EXTRA_GAP_SPREAD_PX)
const float MIN_PULSE_GAP_PX = 1.0f;
const float EXTRA_GAP_SPREAD_PX = 18.0f; // randomness range; set 0 for fixed spacing

// Tail shaping — VERY SOFT EDGES
// Brightness = (0.5 * (1 + cos(pi * (d / (halfLen * EDGE_SOFTNESS))))) ^ GAMMA
const float EDGE_SOFTNESS = 2.0f;      // extend tails
const float PULSE_SHAPE_GAMMA = 0.35f; // <1 = gentler edges

// Temporal fade-in (attack) and fade-out (release)
const uint16_t ATTACK_MS = 1500;        // slow ramp-up
const uint16_t RELEASE_MS = 2000;       // slow fade-out at the end
const float PRE_ENTRY_MARGIN_PX = 6.0f; // spawn further off-strip

// Peak per-pulse (pre-gamma)
const uint8_t PULSE_PEAK_MAX = 160;

// Pulse color (same for all pulses)
const uint8_t PULSE_R = 255, PULSE_G = 0, PULSE_B = 0;

// Twinkles
const uint8_t TWINKLE_COUNT = 10;
const uint8_t TWINKLE_MAX_WHITE = 80;
const uint32_t TWINKLE_PERIOD_MS = 2400;

// ======== WIRING ========
int8_t pins[8] = {DATA_PIN, -1, -1, -1, -1, -1, -1, -1};
Adafruit_NeoPXL8 leds(STRAND_LEN, pins, COLOR_ORDER);

// ======== STATE ========
struct Pulse
{
  float center;     // center position (px)
  float halfLen;    // base half-length (px)
  float drawHalf;   // half-length used for drawing = halfLen * EDGE_SOFTNESS
  uint32_t bornMs;  // for attack envelope
  uint32_t endAtMs; // when rear edge has left the strip (for release window)
};

std::vector<Pulse> pulses;           // active pulses (dynamic)
float nextSpawnRearThreshold = 0.0f; // absolute rear-edge distance target from pixel 0

// float accumulators
float accR[STRAND_LEN], accG[STRAND_LEN], accB[STRAND_LEN], accW[STRAND_LEN];

// timing
uint32_t lastFrameMs = 0;
uint32_t frameCounter = 0; // for dithering phase

// --- Twinkles ---
struct Twinkle
{
  uint16_t pixel;
  int32_t phaseMs;
  float prevPhase;
};
Twinkle twinkles[TWINKLE_COUNT];

// ======== HELPERS ========
static inline uint32_t packColor(uint8_t r, uint8_t g, uint8_t b, uint8_t w)
{
  return leds.Color(r, g, b, w);
}
static inline float frand(float a, float b)
{
  return a + (b - a) * (float)random(0, 10000) / 10000.0f;
}
static inline float randGap()
{
  return MIN_PULSE_GAP_PX + frand(0.0f, EXTRA_GAP_SPREAD_PX);
}
// simple clamp 0..1
static inline float clamp01(float x) { return x < 0 ? 0 : (x > 1 ? 1 : x); }
// cosine ease 0..1 -> 0..1
static inline float easeCos(float u)
{
  if (u <= 0)
    return 0.0f;
  if (u >= 1)
    return 1.0f;
  return 0.5f * (1.0f - cosf((float)M_PI * u));
}
// pseudo-random in [0,1) (for dithering), takes full 32-bit frame counter
static inline float hash01(uint16_t x, uint32_t y)
{
  uint32_t h = 2166136261u;
  h = (h ^ x) * 16777619u;
  h = (h ^ (uint16_t)(y)) * 16777619u;
  h = (h ^ (uint16_t)(y >> 16)) * 16777619u;
  return (h & 0xFFFFFF) / 16777216.0f;
}

// Spawn a new pulse off-strip (to the left)
void spawnPulse()
{
  Pulse p;
  p.halfLen = frand(PULSE_HALFLEN_MIN_PX, PULSE_HALFLEN_MAX_PX);
  p.drawHalf = p.halfLen * EDGE_SOFTNESS;
  p.center = -(p.drawHalf + PRE_ENTRY_MARGIN_PX); // start very faint
  p.bornMs = millis();

  // travel time until rear edge exits the strip (center - drawHalf > STRAND_LEN)
  float travel = (STRAND_LEN + p.drawHalf + PRE_ENTRY_MARGIN_PX + 12.0f) / fmaxf(PULSE_SPEED, 1.0f);
  p.endAtMs = p.bornMs + (uint32_t)(travel * 1000.0f);

  pulses.push_back(p);

  // Set next rear-edge threshold (absolute distance from start)
  float newestRear = fmaxf(0.0f, p.center - p.drawHalf); // negative at spawn -> 0
  nextSpawnRearThreshold = newestRear + randGap();
}

void initTwinkles()
{
  for (uint8_t i = 0; i < TWINKLE_COUNT; i++)
  {
    twinkles[i].pixel = random(0, STRAND_LEN);
    twinkles[i].phaseMs = random(0, TWINKLE_PERIOD_MS);
    twinkles[i].prevPhase = 0.0f;
  }
}
static inline void relocateTwinkleToStart(Twinkle &t, uint32_t nowMs)
{
  t.pixel = random(0, STRAND_LEN);
  t.phaseMs = -(int32_t)(nowMs % TWINKLE_PERIOD_MS);
  t.prevPhase = 0.0f;
}

void renderFrame(float dt)
{
  // clear accumulators
  for (int i = 0; i < STRAND_LEN; i++)
    accR[i] = accG[i] = accB[i] = accW[i] = 0.0f;

  const float peakR = (PULSE_R / 255.0f) * (PULSE_PEAK_MAX / 255.0f);
  const float peakG = (PULSE_G / 255.0f) * (PULSE_PEAK_MAX / 255.0f);
  const float peakB = (PULSE_B / 255.0f) * (PULSE_PEAK_MAX / 255.0f);

  uint32_t nowMs = millis();

  // Advance & draw pulses; remove those that have fully passed
  for (size_t i = 0; i < pulses.size(); /* increment inside */)
  {
    Pulse &p = pulses[i];

    // move
    p.center += PULSE_SPEED * dt;

    // cull if done (rear edge beyond strip)
    if (nowMs > p.endAtMs || (p.center - p.drawHalf) > (STRAND_LEN + 1))
    {
      pulses.erase(pulses.begin() + i);
      continue;
    }

    // Temporal envelopes:
    // Attack  : 0→1 over ATTACK_MS from bornMs
    float attack = easeCos((float)(nowMs - p.bornMs) / (float)ATTACK_MS);

    // ✅ Correct release: 1→0 over the *last* RELEASE_MS before endAtMs
    int32_t tToEnd = (int32_t)p.endAtMs - (int32_t)nowMs; // ms until end
    float u = clamp01((float)tToEnd / (float)RELEASE_MS); // 1..0 over final window
    float release = easeCos(u);                           // high until close to the end, then eases down

    float env = attack * release;

    // Draw pulse with very soft spatial falloff
    int start = (int)floorf(p.center - p.drawHalf);
    int end = (int)ceilf(p.center + p.drawHalf);
    if (start < 0)
      start = 0;
    if (end > STRAND_LEN)
      end = STRAND_LEN;

    for (int px = start; px < end; px++)
    {
      float d = fabsf((float)px - p.center); // 0 at center → drawHalf at edges
      float x = d / p.drawHalf;              // 0..1
      if (x > 1.0f)
        continue;

      // Extremely soft raised-cosine with gamma < 1
      float bSpatial = powf(0.5f * (1.0f + cosf((float)M_PI * x)), PULSE_SHAPE_GAMMA);
      float b = env * bSpatial;

      accR[px] += peakR * b;
      accG[px] += peakG * b;
      accB[px] += peakB * b;
    }

    ++i;
  }

  // Spawn rule: first pulse immediately; then by rear-edge distance
  if (pulses.empty())
  {
    spawnPulse();
  }
  else
  {
    const Pulse &newest = pulses.back();
    float newestRear = newest.center - newest.drawHalf; // rear (left) edge
    float traveledFromStart = fmaxf(0.0f, newestRear);
    if (traveledFromStart >= nextSpawnRearThreshold)
    {
      spawnPulse();
    }
  }

  // Twinkles
  for (uint8_t i = 0; i < TWINKLE_COUNT; i++)
  {
    Twinkle &t = twinkles[i];
    float phase = (float)((int32_t)(nowMs + t.phaseMs) % (int32_t)TWINKLE_PERIOD_MS) / (float)TWINKLE_PERIOD_MS;
    if (t.prevPhase > 0.9f && phase < 0.1f)
    {
      relocateTwinkleToStart(t, nowMs);
      phase = 0.0f;
    }
    t.prevPhase = phase;

    float s = 0.5f * (1.0f - cosf(phase * 2.0f * (float)M_PI)); // 0..1
    float w = (s * TWINKLE_MAX_WHITE) / 255.0f;

    int px = t.pixel;
    if (px >= 0 && px < STRAND_LEN)
      accW[px] = fmaxf(accW[px], w);
  }

  // Quantize once, with gamma + light temporal dithering (long period)
  leds.clear();
  for (int px = 0; px < STRAND_LEN; px++)
  {
    float r = fminf(accR[px], 1.0f);
    float g = fminf(accG[px], 1.0f);
    float b = fminf(accB[px], 1.0f);
    float w = fminf(accW[px], 1.0f);

    float thr = hash01(px, frameCounter); // 0..1

    float r255 = r * 255.0f;
    uint8_t r8 = (uint8_t)floorf(r255 + ((r255 - floorf(r255)) > thr ? 1.0f : 0.0f));
    float g255 = g * 255.0f;
    uint8_t g8 = (uint8_t)floorf(g255 + ((g255 - floorf(g255)) > thr ? 1.0f : 0.0f));
    float b255 = b * 255.0f;
    uint8_t b8 = (uint8_t)floorf(b255 + ((b255 - floorf(b255)) > thr ? 1.0f : 0.0f));
    float w255 = w * 255.0f;
    uint8_t w8 = (uint8_t)floorf(w255 + ((w255 - floorf(w255)) > thr ? 1.0f : 0.0f));

    r8 = leds.gamma8(r8);
    g8 = leds.gamma8(g8);
    b8 = leds.gamma8(b8);
    w8 = leds.gamma8(w8);

    leds.setPixelColor(px, packColor(r8, g8, b8, w8));
  }
}

// ======== ARDUINO ========
void setup()
{
  randomSeed(analogRead(28));
#ifdef PIN_NEOPIXEL_POWER
  pinMode(PIN_NEOPIXEL_POWER, OUTPUT);
  digitalWrite(PIN_NEOPIXEL_POWER, LOW);
#endif

  if (!leds.begin())
  {
    pinMode(LED_BUILTIN, OUTPUT);
    for (;;)
      digitalWrite(LED_BUILTIN, (millis() / 200) & 1);
  }
  leds.setBrightness(255);
  leds.clear();
  leds.show();

  initTwinkles();
  pulses.clear();
  spawnPulse(); // start with one pulse
  lastFrameMs = millis();
}

void loop()
{
  uint32_t now = millis();
  float dt = (now - lastFrameMs) / 1000.0f;
  if (dt < 0.001f)
    dt = 0.001f;
  if (dt > 0.050f)
    dt = 0.050f;

  renderFrame(dt);
  leds.show();

  frameCounter++; // advance dithering phase
  lastFrameMs = now;
  delay(16); // ~60 FPS
}

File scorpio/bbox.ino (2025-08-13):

/*
  SCORPIO + Adafruit_NeoPXL8 framed USB control
  - 8 strands, 144 pixels each, GRBW
  - USB CDC protocol:
      [0xAA][len_hi][len_lo][payload ...][chk]
      payload is N * 6 bytes: [si, pi, r, g, b, w]
      chk = XOR of all payload bytes
*/

#include <Adafruit_NeoPXL8.h>
#include <vector>
#include <math.h>

// -------- Configuration --------
#define NUM_STRANDS 8
#define STRAND_LEN 144
#define COLOR_ORDER NEO_GRBW

// SCORPIO RP2040 PIO pins (GP16..GP23)
int8_t pins[8] = {16, 17, 18, 19, 20, 21, 22, 23};

// -------- Globals --------
Adafruit_NeoPXL8 leds(STRAND_LEN, pins, COLOR_ORDER);

std::vector<uint8_t> buf; // rolling USB buffer

// Protocol constants
const uint8_t START = 0xAA;

// add near the top (globals)
static uint32_t front_stamp_ms = 0;
static const uint32_t FRAME_STUCK_MS = 200;                             // resync window
static const uint32_t MAX_LEN = (uint32_t)NUM_STRANDS * STRAND_LEN * 6; // hard cap

// -------- Helpers --------
static inline uint32_t packGRBW(uint8_t r, uint8_t g, uint8_t b, uint8_t w)
{
  // Adafruit_NeoPXL8 uses the same Color() signature as NeoPixel (RGB or RGBW).
  return leds.Color(r, g, b, w);
}

// Heartbeat on built-in LED (no PIO/NeoPixel usage)
void heartbeat()
{
  static uint32_t t0 = millis();
  float t = (millis() - t0) / 1000.0f;
  float pulse = (sinf(2.0f * M_PI * t) + 1.0f) * 0.5f; // 0..1
  int duty = (int)(pulse * 255.0f);

  // Prefer PWM if available on LED_BUILTIN; otherwise fall back to binary
  analogWrite(LED_BUILTIN, duty);
}

bool parseAndApplyFrames()
{
  bool changed = false;

  for (;;)
  {
    if (buf.size() < 4)
      break; // need start + len_hi + len_lo + chk(min)

    // Resync until we find a START at front
    if (buf[0] != START)
    {
      buf.erase(buf.begin());
      front_stamp_ms = 0;
      continue;
    }

    // Have a START; if this is a new candidate frame, start a timer
    if (front_stamp_ms == 0)
      front_stamp_ms = millis();

    // read length
    uint16_t length = ((uint16_t)buf[1] << 8) | buf[2];

    // Sanity checks — drop the START and resync on bogus lengths
    if (length == 0 || length > MAX_LEN || (length % 6u) != 0u)
    {
      // bad frame header; drop START and try next byte
      buf.erase(buf.begin());
      front_stamp_ms = 0;
      continue;
    }

    uint32_t total = 3u + length + 1u; // start + len(2) + payload + chk
    if (buf.size() < total)
    {
      // Not enough data yet. If it's been too long, assume corrupted header and resync.
      if (millis() - front_stamp_ms > FRAME_STUCK_MS)
      {
        buf.erase(buf.begin()); // drop START; try to find next one
        front_stamp_ms = 0;
      }
      break; // wait for more bytes
    }

    // Verify checksum
    uint8_t x = 0;
    for (uint32_t i = 0; i < length; i++)
      x ^= buf[3 + i];
    uint8_t chk = buf[3 + length];

    if (x == chk)
    {
      // Apply pixels
      for (uint32_t i = 3; i < 3u + length; i += 6)
      {
        uint8_t si = buf[i + 0];
        uint8_t pi = buf[i + 1];
        uint8_t r = buf[i + 2];
        uint8_t g = buf[i + 3];
        uint8_t b = buf[i + 4];
        uint8_t w = buf[i + 5];
        if (si < NUM_STRANDS && pi < STRAND_LEN)
        {
          uint32_t idx = (uint32_t)si * STRAND_LEN + pi;
          leds.setPixelColor(idx, leds.Color(r, g, b, w));
          changed = true;
        }
      }
    }
    // Drop processed (or bad‑checksum) frame and reset timer
    buf.erase(buf.begin(), buf.begin() + total);
    front_stamp_ms = 0;
  }
  return changed;
}

// -------- Arduino lifecycle --------
void setup()
{
  // USB serial
  Serial.begin(115200);
  // Give USB a moment on cold-boot; non-blocking if already up.
  uint32_t tstart = millis();
  while (!Serial && (millis() - tstart < 1500))
  {
  }

  // Heartbeat LED (built-in)
  pinMode(LED_BUILTIN, OUTPUT);
  analogWrite(LED_BUILTIN, 128); // mid brightness on boot

  // NeoPXL8 start
  if (!leds.begin())
  {
    pinMode(LED_BUILTIN, OUTPUT);
    for (;;)
      digitalWrite(LED_BUILTIN, (millis() / 250) & 1); // fatal blink
  }
  leds.setBrightness(255); // full; adjust if needed

  // Startup: all red (R channel) for 1 second, then clear
  leds.fill(packGRBW(255, 0, 0, 0));
  leds.show();
  delay(2000);
  leds.clear();
  leds.show();

  buf.reserve(4096);
}

void loop()
{
  heartbeat();

  // Pull any available USB bytes into rolling buffer
  while (Serial.available() > 0)
  {
    buf.push_back((uint8_t)Serial.read());
    // Prevent unbounded growth on junk input
    if (buf.size() > 65536)
      buf.erase(buf.begin(), buf.begin() + 32768);
  }

  bool changed = parseAndApplyFrames();

  if (changed)
  {
    leds.show();
  }

  // Tiny pause keeps loop snappy without starving USB
  // (lower CPU, but still very responsive)
  delay(1);
}

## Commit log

2017-05-05 moved render code out of keyboard
    data flow is:
    keyboard => loop => [audio | render]
2017-05-18 separate leds pkg, revert termbox.close change
2017-05-19 working LEDS with sound ! fixed colors
2017-05-24 testing 330 LEDs
2017-06-06 add button decay
2017-06-06 writechan module, wg in leds, keymap consistency
2017-06-06 led ticks
2017-06-18 move leds cmd
2017-06-19 LEDs only cmd cleanup
2017-06-29 init both PIN1's on PWM0
2017-08-02 add crane script, led refactor
2017-08-03 fix clear for new led api
2017-08-03 integrated gpio button into fish script
2017-08-03 led and record fixups
2017-08-08 bbox leds wip
2017-08-08 led intervals wip
2017-08-08 bbox beats calibrated
2017-08-08 render freeform leds
2017-08-14 led positions
2017-08-20 adjust led refresh interval based on bpm
2017-09-14 pwm and boot time notes
2017-10-02 reference new vids, fritzing projects
    [fish_fritzing.fzz]
2017-10-02 fish vid, sketchup file, no more todos
    [bbox_sketchup.skp]
2018-07-08 first cut harness
2018-07-09 program switching
2018-07-10 ceottk: ignore buttons when playing audio
2018-07-10 Program switching, with start/stop
2018-07-12 web rendered first cut
2018-07-15 add switching back
2018-07-15 wired up ceottk to new interface
2018-07-15 stop wavs on program switch
2018-07-17 wire up web renderer
2018-07-28 Introduce fishweb, fish leds wired up to web
2018-07-29 wired up LEDs to new beatboxer programs
2018-08-01 fishweb first cut
2018-08-07 set front leds for baux
2018-08-08 force colors on edge of wheel
2018-08-08 misc field updates
    ceottk: decrease impatience threshold from 100 to 20
    ceottk: set 3 minute timeout threshold
    beatboxer: decrease yield threshold from 75% to 50% of buttons
    beatboxer: disable web view in led prod mode
    beatboxer: add flag to dynamically set keyboard mapping
    web: add notes to calculate opposite rgb value
2018-08-12 HeatColor wip
2018-08-12 fix heat colors
2018-08-17 disable web interface for bbox LEDs program
2018-08-25 put globe on independent led output
2025-05-25 process non-printable key presses
2025-05-26 update pi usb device path
2025-05-26 onboard status LED
2025-06-14 leds rgbw
2025-06-15 Better leds API
2025-06-15 led state mgmt
2025-06-15 LED state
2025-06-25 thread safe audio
2025-06-26 runtime support for pi vs. mac device
2025-06-26 led beats testing
2025-06-27 better keep alive and tempo decay timers
2025-06-27 decay timers in select loop
2025-06-27 better decay timers
2025-06-27 graceful LED handling
2025-06-27 abstract led strip indexes from beats
2025-06-27 led test fixup
2025-06-27 30 LED test strip config
2025-06-29 diff'ing and batching LED commands
2025-06-29 led concurrency updates
2025-07-01 better LED framerate
2025-07-13 Add instructions and code for DMV LEDs
2025-07-22 mac led updates
2025-07-23 approximate row LEDs
2025-07-28 cut off strip lengths
2025-07-28 cut off main strips
2025-08-08 arduino first commit
2025-08-08 working arduino bbox code
2025-08-08 30 radius pulse, trace logging
2025-08-08 clean up arduino readme
2025-08-09 wire up PlayWithEQ in program interface
2025-08-09 button eq song integration
2025-08-12 introduce baux arduino
2025-08-12 remove trace
2025-08-12 clear baux LEDs before update
2025-08-12 scorpio status LED update
2025-08-13 restart capture device if audio stops sending
2025-08-17 modify cmd/leds for baux
2025-09-13 Updated docs for 2025
    [bbox2025_fritzing.fzz]
